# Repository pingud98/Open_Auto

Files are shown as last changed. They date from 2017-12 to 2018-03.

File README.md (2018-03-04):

# Open_Auto

Open Auto is an open hardware car sharing hardware platform designed for use by local car-sharing co-operatives and community associations. It originally started out as a Pi Hat, but has now changed into a standalone IOT device based on communications hardware from Particle.

The functionality is simple:
1) GPS tracking, allowing the car to be located at all times and used to update the onboard Real-time Clock (RTC)
2) RFID card access (125kHz or other frequency, requires an external module), with either CAN-bus or relays to open/close the car doors
3) Accelerometer to check driving style (requires an Electron)
4) RTC to allow for power saving (wake up once per minute to check status instead of continuously being on)
5) CAN bus interface for automotive communication
6) Particle Electron/Photon socket for Wi-Fi and/or Cellular connectivity
7) An SD card slot for data logging.
8) An I2C header for whatever else you want to connect.

We're currently working on a software stack for the Electron/Photon that will allow all the basic functions to be accessed via the particle API.

The design also includes a case, which you can make in 3mm acrylic. 

This design is licensed under the CERN Open Hardware License V1.2

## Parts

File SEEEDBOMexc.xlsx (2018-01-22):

Designator | Manufacturer Part Number | Quantity
J1 | A-DS 09 A/KG-T2S | 1
K1 | 311020024 | 1
RELAY1, RELAY2 | HLS8L-DC5V-S-C | 2
CHANNEL1, CHANNEL2 | GS009S-5.0-03P-11 | 2
R17 | RC0603JR-07100RL | 1
C1, C5, C8, C9, C12, C14, C16, C19, C22 | CC0603KRX7R9BB104 | 9
R3, R6, R18, R20, R32 | RC0603JR-0710KL | 5
R8, R9 | RC0603JR-0710RL | 2
C6, C21 | CC0603MRX5R5BB106 | 2
C17, C18 | CC0603JRNPO9BN100 | 2
C10 | CC0805KKX5R8BB106 | 1
R2, R7, R19 | RC0603FR-071KL | 3
D8 | 1SMB16CAT3G | 1
C3 | CC0603KRX7R8BB105 | 1
D5, D6 | B5819W | 2
C7 | CC0805MKX5R5BB226 | 1
R10, R11, R12, R13 | RC0603JR-073K9L | 4
R24, R25 | RC0603JR-072K2L | 2
C4 | C0805C474K5RACTU | 1
J3 | F185-1104A1BSYA1 | 1
R1 | RC0603FR-0768KL | 1
CN1, CN2, CN3 | F185-1106A1BSYC1 | 3
CN4, CN5 | P125-1103A1BS116A1 | 2
R21, R31, R33 | RC0603JR-074K7L | 3
U5 | A2235-H | 1
X4 | FC-135 | 1
D7 | BAT54S-7-F | 1
D12, D13 | 19-217-BHC-ZL1M2RY-3T | 2
BAT1 | BS-12-B3AA003 | 1
C11 | GRM219R61A226MEA0D | 1
D2, D3 | 1N4148 | 2
U3 | MMA7660FCR1 | 1
IC1 | NC7SZ14M5X | 1
IC3 | NCP1117LPST50T3G | 1
U8 | PCF85063TP/1Z | 1
D4 | PESD1CAN,215 | 1
D10, D11 | 19-217-R6C-AL1M2VY-3T | 2
D9 | RS1J-E3/5AT | 1
IC2 | TJA1049T-118 | 1
SDCARD | 1040310811 | 1
Q1, Q2 | S9013 | 2
P1, P2 | PPTC181LFBN-RC | 2
JP1, JP2 | 320190003 | 2

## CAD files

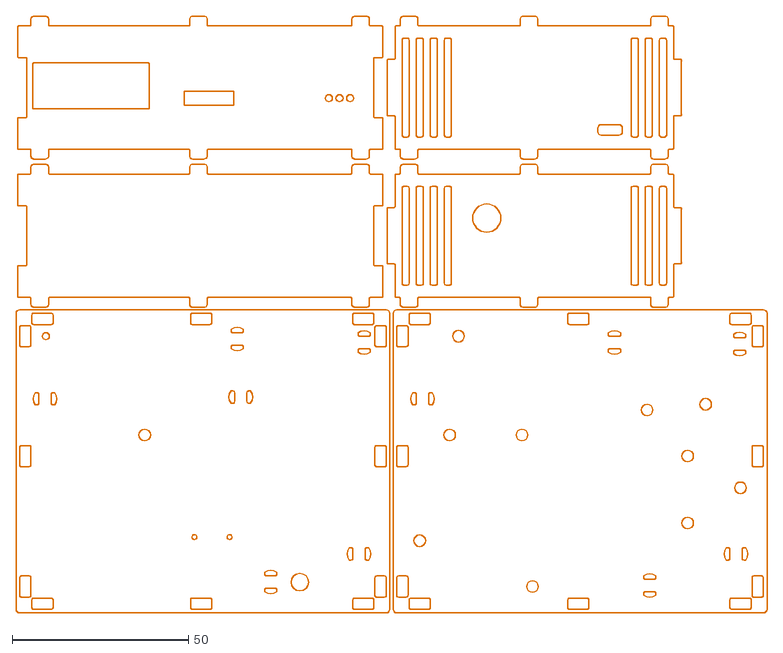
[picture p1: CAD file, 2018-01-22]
openautocaseproduction.dxf
213.0 x 169.3

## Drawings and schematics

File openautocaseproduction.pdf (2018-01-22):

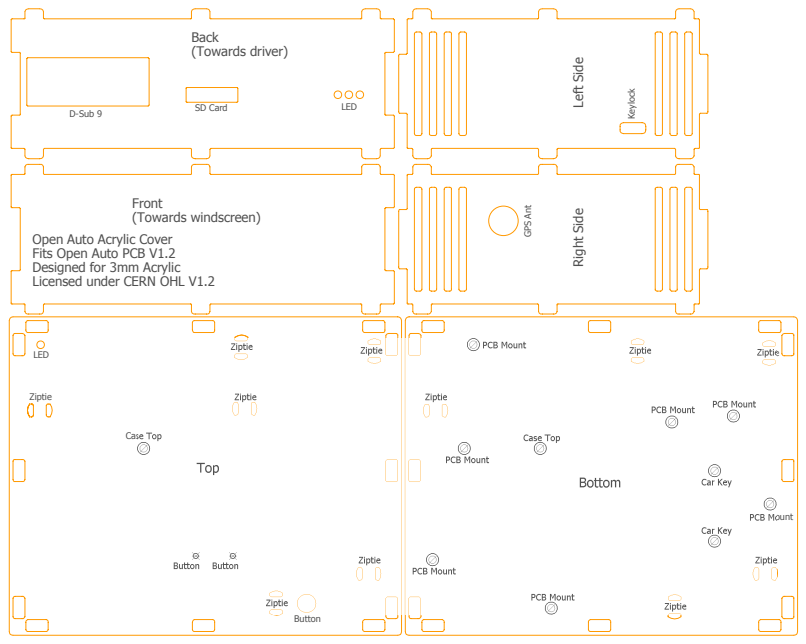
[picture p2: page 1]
Ziptie; Case Top; LED; Button; GPS Ant; D-Sub 9; Keylock; SD Card; Front (Towards windscreen); Back (Towards driver)

Right Side Left Side

Open Auto Acrylic Cover
Fits Open Auto PCB V1.2
Designed for 3mm Acrylic
Licensed under CERN OHL V1.2

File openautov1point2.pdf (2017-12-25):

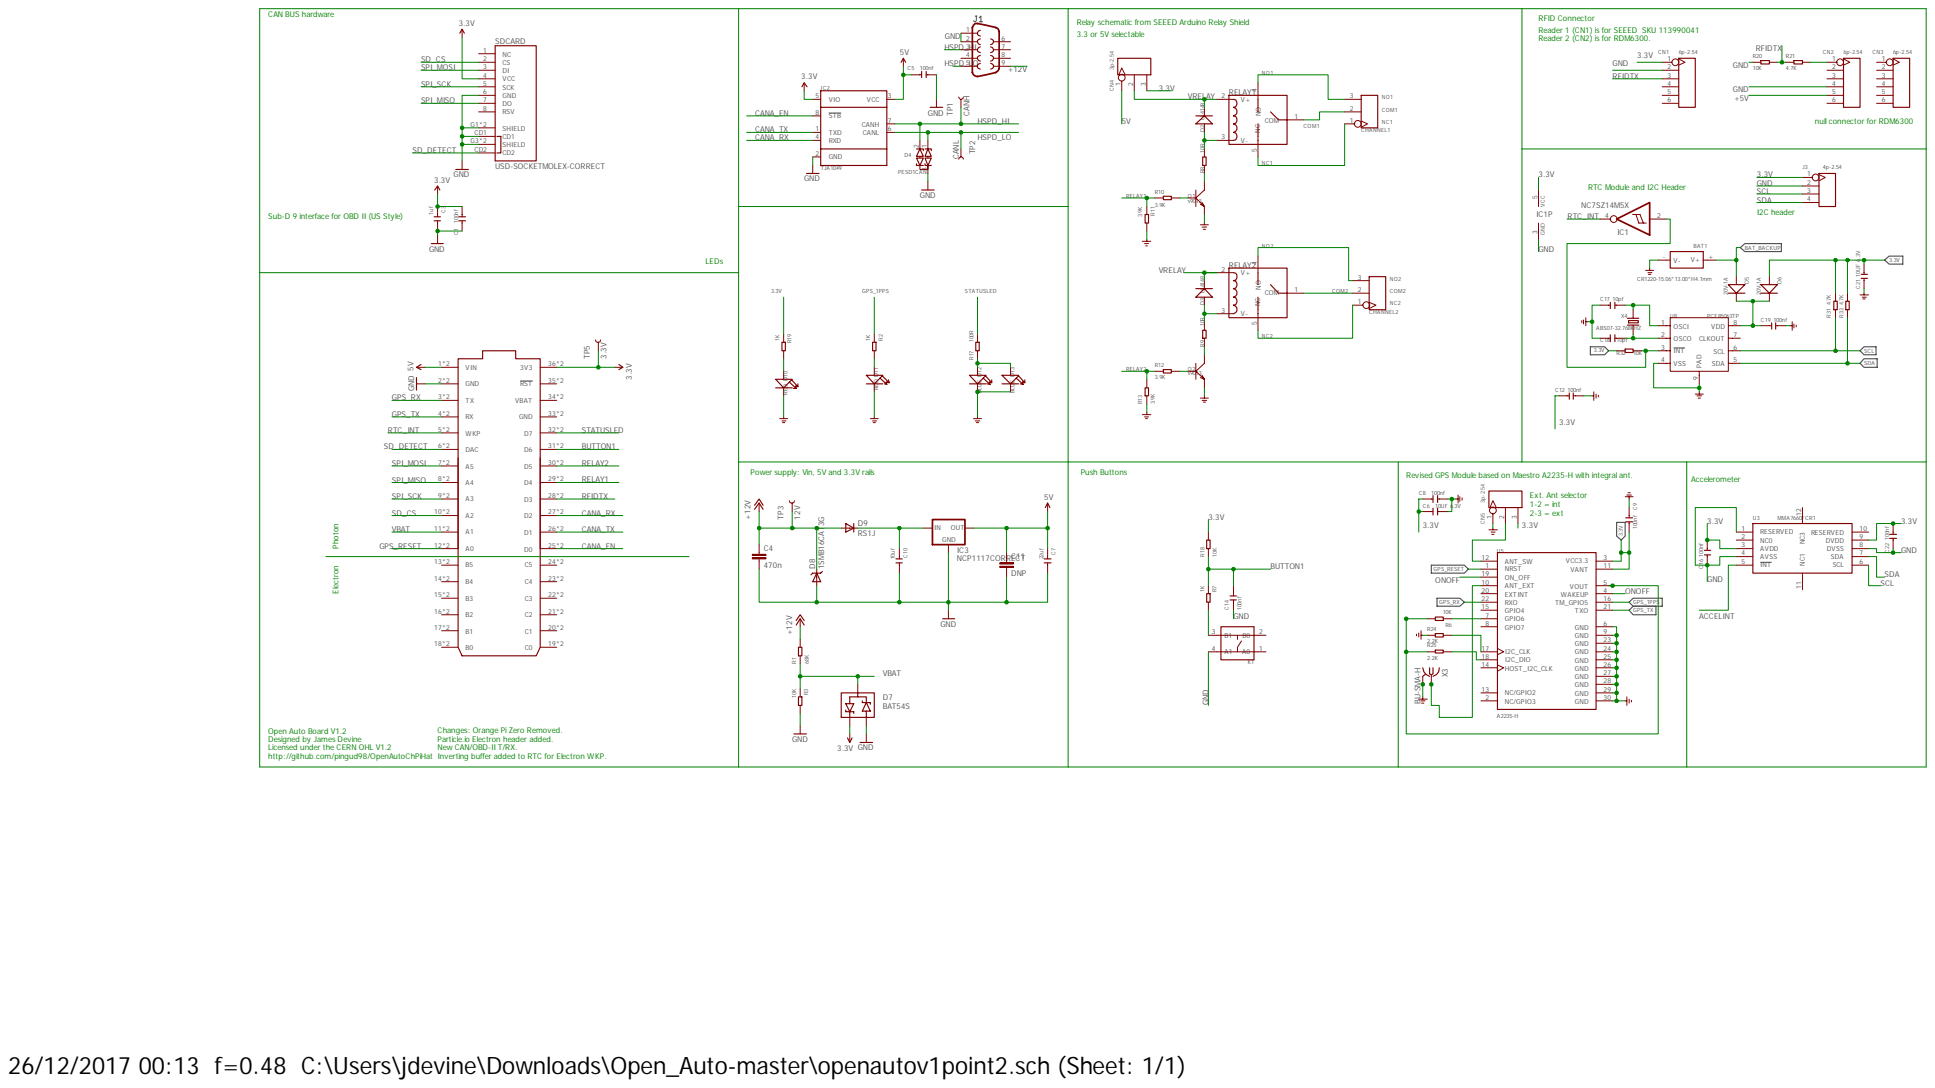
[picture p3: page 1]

Reader 1 (CN1) is for SEEED SKU 113990041
Reader 2 (CN2) is for RDM6300.

RTC Module and I2C Header

Sub-D 9 interface for OBD II (US Style)

Power supply: Vin, 5V and 3.3V rails

Revised GPS Module based on Maestro A2235-H with integral ant.

Open Auto Board V1.2
Designed by James Devine
Licensed under the CERN OHL V1.2
http://github.com/pingud98/OpenAutoChPiHat

Changes: Orange Pi Zero Removed.
Particle.io Electron header added.
New CAN/OBD-II T/RX.
Inverting buffer added to RTC for Electron WKP.

26/12/2017 00:13 f=0.48 C:\Users\jdevine\Downloads\Open_Auto-master\openautov1point2.sch (Sheet: 1/1)

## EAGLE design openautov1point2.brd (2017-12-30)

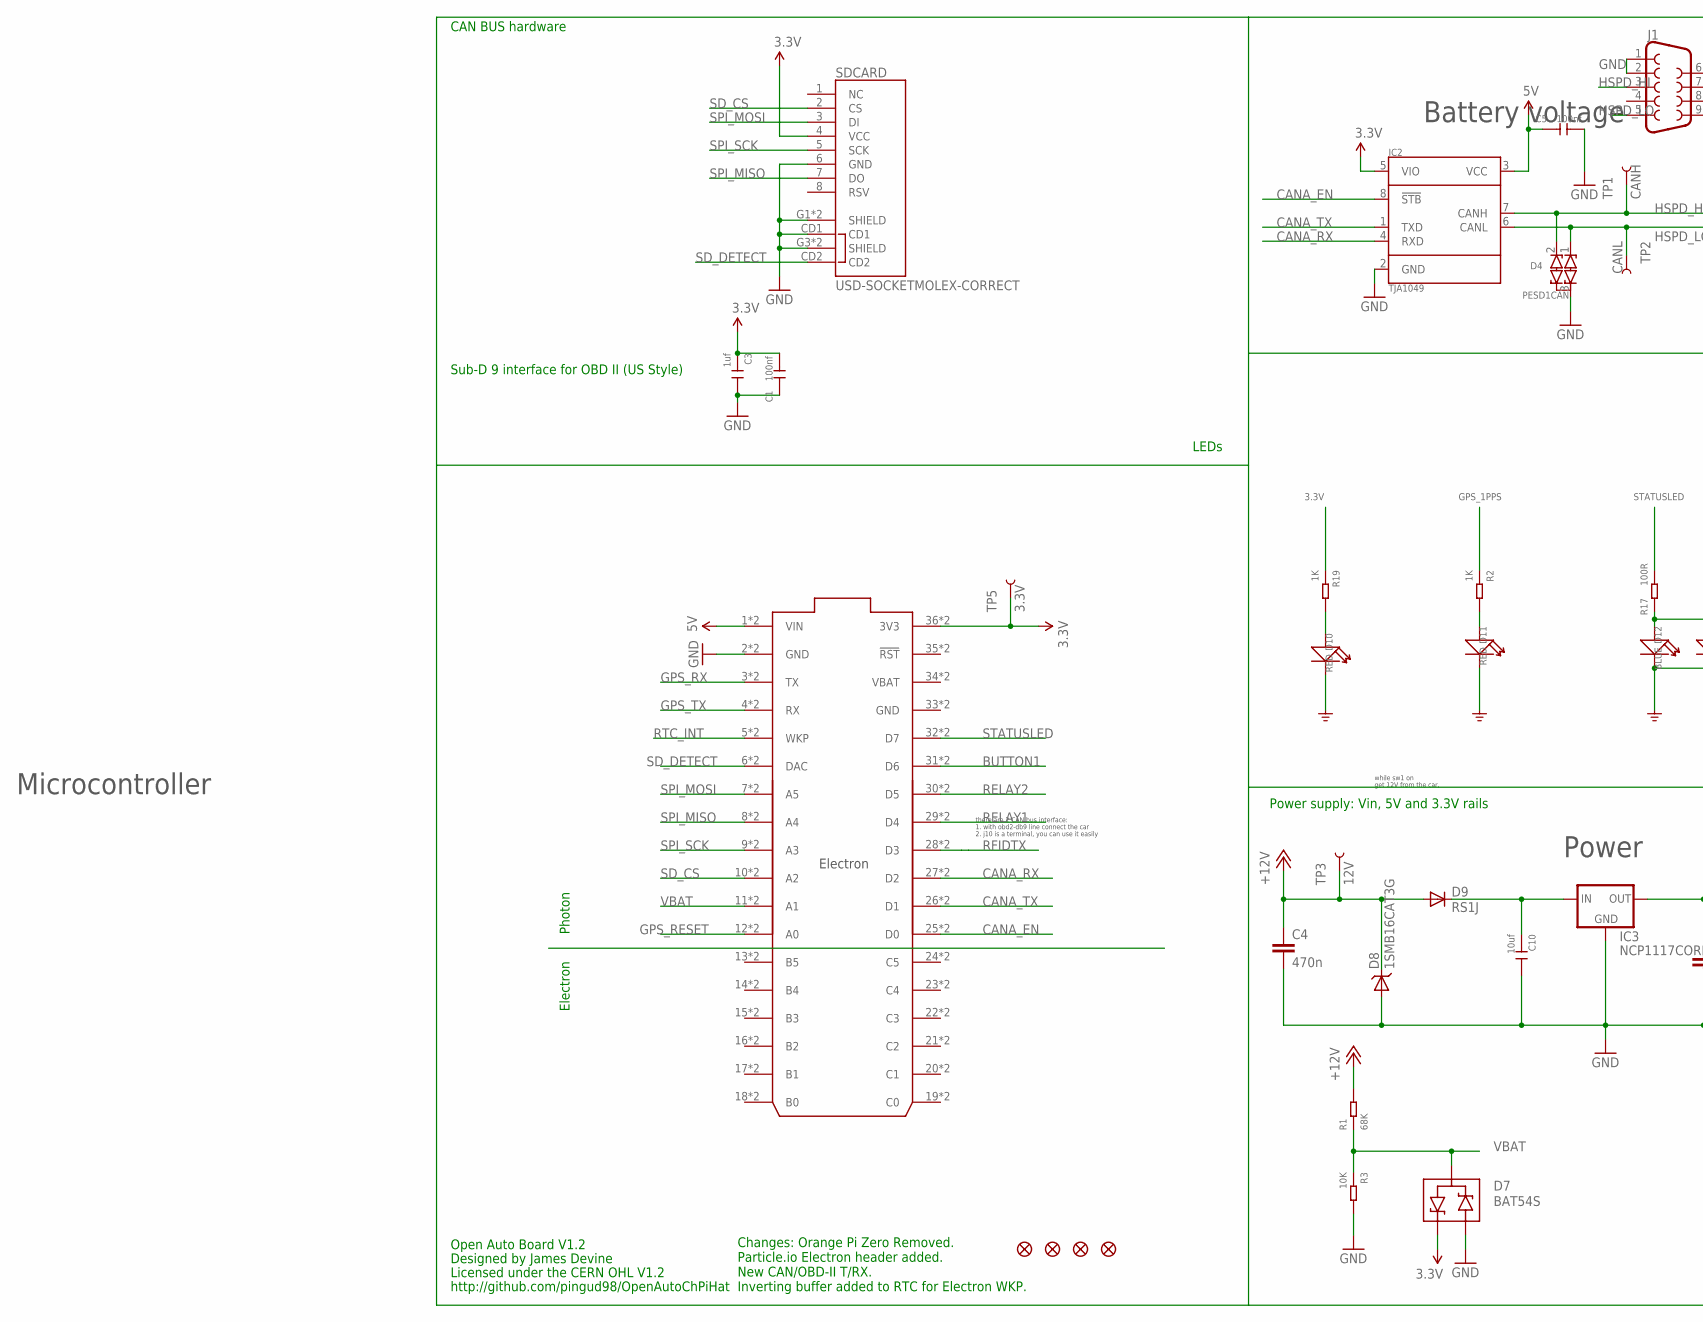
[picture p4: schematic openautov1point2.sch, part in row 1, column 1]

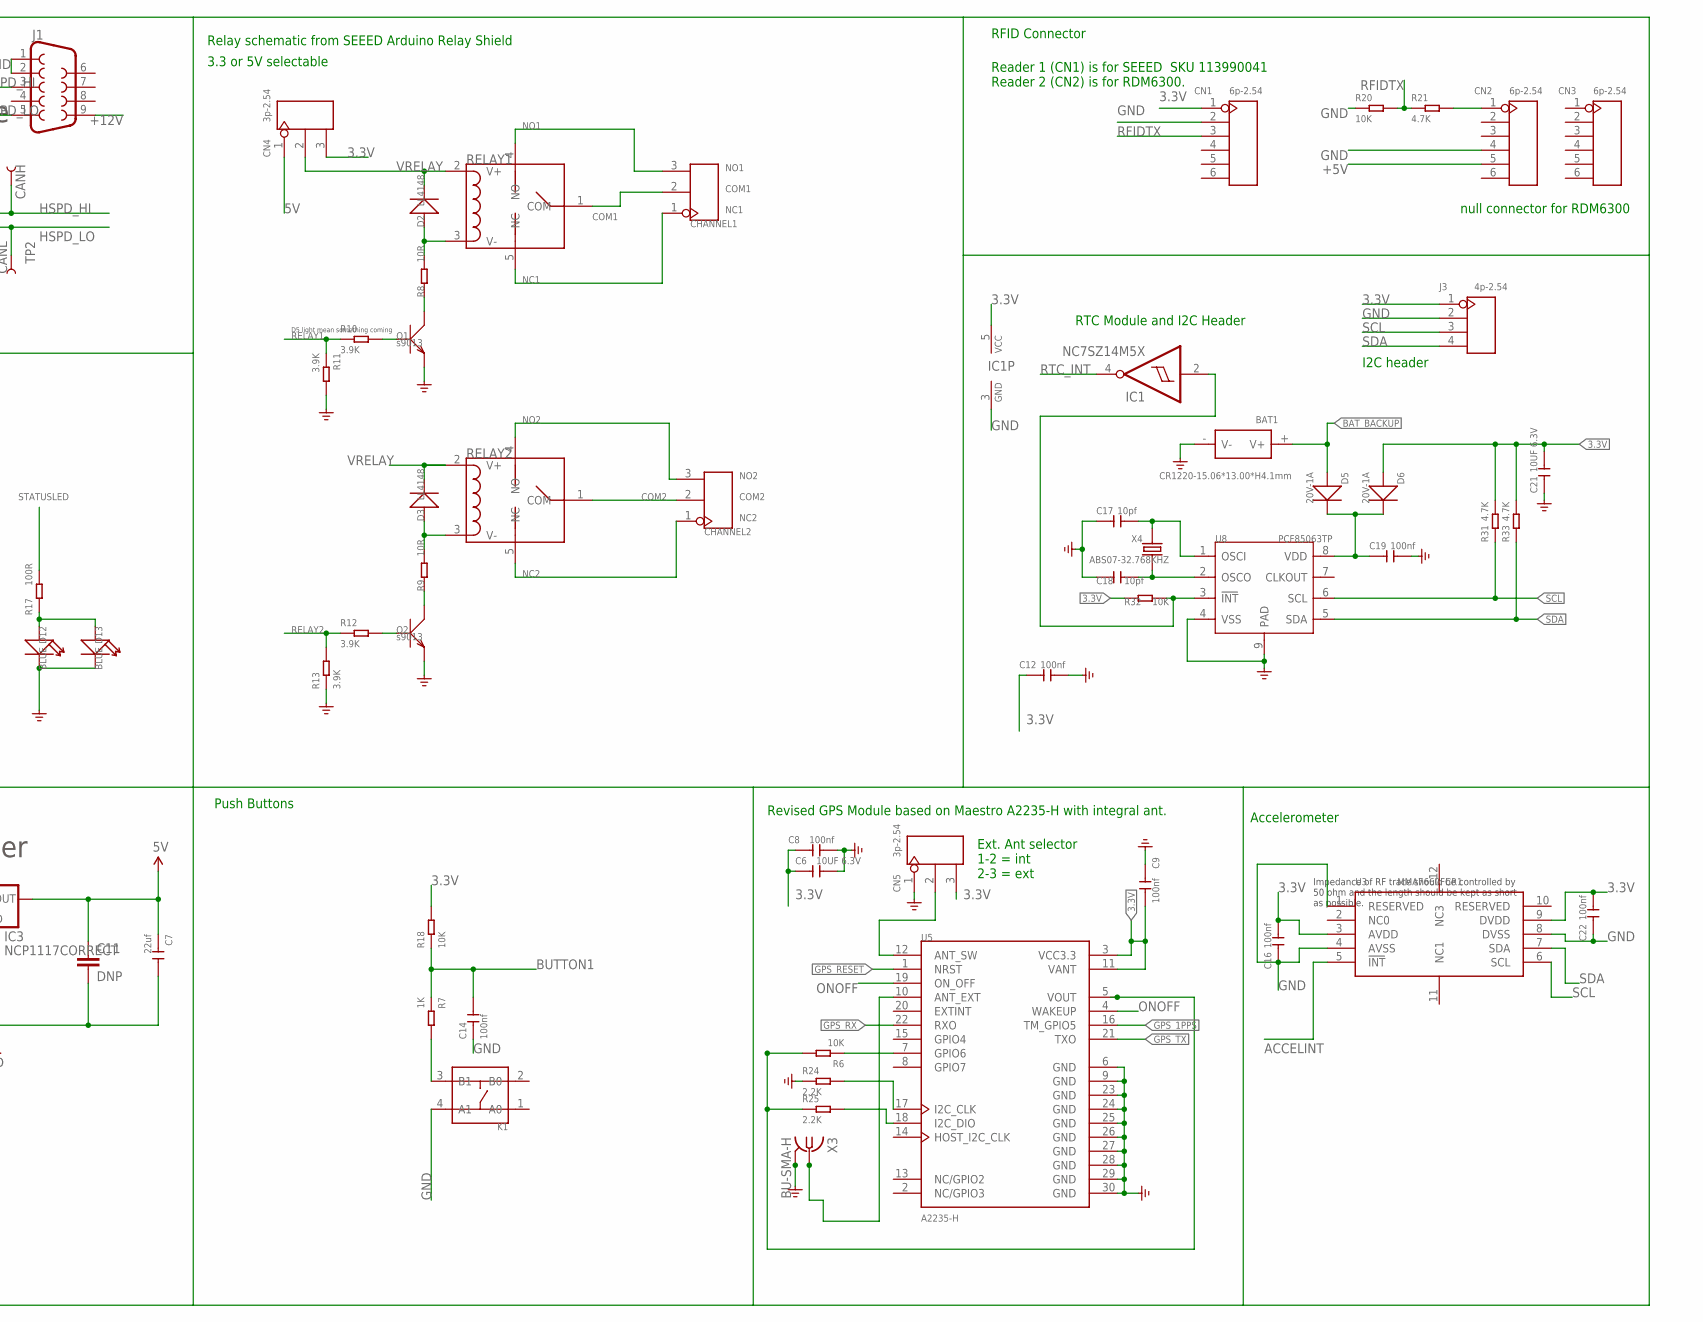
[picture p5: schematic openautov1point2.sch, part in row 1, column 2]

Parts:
BAT1: CR1220-15.06*13.00*H4.1mm; BAT2P-SMD-16.4-CR1220
C1, C5, C8, C9, C12, C14, C16, C19, C22: 100nf; C0603
C3: 1uf; C0603; PARTNO CC0805KKX7R7BB105
C4: 470n; C0805; PARTNO C0805C474K5RACTU
C6, C21: 10UF 6.3V; C0603
C7: 22uf; C0805; PARTNO GRM219R61A226MEA0D
C10: 10uf; C0805; PARTNO GRM21BR6YA106KE43L
C11: DNP; C0805; PARTNO GRM219R61A226MEA0D
C17, C18: 10pf; C0603
CHANNEL1, CHANNEL2: SCREW-TERMINAL-3P'3.5'; 3P-3.5
CN1, CN2, CN3: 6p-2.54; H6-2.54
CN4, CN5: 3p-2.54; H3-2.54
D2, D3: LL4148; LL-34
D4: PESD1CAN; SOT23; PARTNO PESD1CAN-215
D5, D6: 20V-1A; SOD-123
D7: BAT54S; SOT23; PARTNO BAT54S-7-F
D8: 1SMB16CAT3G; SMB-DIODE; PARTNO 1SMB16CAT3G
D9: RS1J; SMA-DIODE; PARTNO RS1J-E3/5AT
D10, D11: RED; LED-0603
D12, D13: BLUE; LED-0603
ELECTRON: ELECTRON_WITH_EXTERNAL_HEADERS; ELECTRON_EXTERNAL; PARTNO PPTC181LFBN-RC
FID1, FID2, FID3, FID4: FIDUCIAL1.5X3; FIDUCIAL-1.5X3
IC1: NC7SZ14M5X; SOT23-5
IC2: TJA1049; SO8; PARTNO TJA1049T-118
IC3: NCP1117CORRECT; SOT223; PARTNO NCP1117LPST50T3G
J1: DB9MALE; DB9_MALE
J3: 4p-2.54; H4-2.54
K1: DIP-SWITCH-TACTILE-SPST-NO/TS-1109(4P-D6.0MM)'TS-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; SW4-6.0X6.0X5.0MM
Q1, Q2: s9013; SOT23
R1: 68K; R0603; PARTNO ERJ-6ENF6202V
R2, R7, R19: 1K; R0603
R3, R6, R18, R20, R32: 10K; R0603
R8, R9: 10R; R0603
R10, R11, R12, R13: 3.9K; R0603
R17: 100R; R0603
R21, R31, R33: 4.7K; R0603
R24, R25: 2.2K; R0603
RELAY1, RELAY2: RELAY-HLS8L-DC5V-S-C; 5P-19.0X15.5X15.8H
SDCARD: USD-SOCKETMOLEX-CORRECT; MICRO-SD-MOLEX-CORRECT; PARTNO 1040310811
TP1: CANH; PAD.03X.03
TP2: CANL; PAD.03X.03
TP3: 12V; PAD.03X.03
TP5: 3.3V; PAD.03X.03
U3: MMA7660FCR1; DFN10-0.5-3.0X3.0MM
U5: A2235-H; XCVR_A2235-H
U8: PCF85063TP; HWSON8-0.5-2X3X0.75MM
X3: BU-SMA-H
X4: ABS07-32.768KHZ; X2-SMD-3.2X1.5X0.55MM

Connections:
3.3V: C1.2, C3.1, C6.1, C8.1, C9.2, C12.1, C16.2, C21.2, C22.2, CN1.1, CN4.3, D6.+, D7.2 (C1), ELECTRON.36 (3V3), ELECTRON.@36 (3V3), IC1.5 (VCC), IC2.5 (VIO), J3.1, R18.2, R19.1, R31.2, R32.1, R33.2, SDCARD.4 (VCC), TP5.P$1, U3.3 (AVDD), U3.9 (DVDD), U5.3 (VCC3.3), U5.11 (VANT)
5V: C5.1, C7.1, C11.1, CN4.1, ELECTRON.1 (VIN), ELECTRON.@1 (VIN), IC2.3 (VCC), IC3.2 (OUT), IC3.4 (OUT)
!RTC_INT: IC1.2 (I), R32.2, U8.3 (!INT)
+5V: CN2.5
+12V: C4.1, D8.C, D9.A, J1.9, R1.2, TP3.P$1
ACCELINT: U3.5 (!INT)
BAT_BACKUP: BAT1.+ (V+), D5.+
BUTTON1: C14.2, ELECTRON.31 (D6), ELECTRON.@31 (D6), R7.1, R18.1
CANA_EN: ELECTRON.25 (D0), ELECTRON.@25 (D0), IC2.8 (!STB)
CANA_RX: ELECTRON.27 (D2), ELECTRON.@27 (D2), IC2.4 (RXD)
CANA_TX: ELECTRON.26 (D1), ELECTRON.@26 (D1), IC2.1 (TXD)
COM1: CHANNEL1.2, RELAY1.1 (COM)
COM2: CHANNEL2.2, RELAY2.1 (COM)
GND: BAT1.- (V-), C1.1, C3.2, C4.2, C5.2, C6.2, C7.2, C8.2, C9.1, C10.2, C11.2, C12.2, C14.1, C16.1, C17.1, C18.1, C19.2, C21.1, C22.1, CN1.2, CN2.4, CN5.1, D4.3 (COM), D7.1 (A2), D8.A, D10.-, D11.-, D12.-, D13.-, ELECTRON.2 (GND), ELECTRON.33 (GND), ELECTRON.@2 (GND), ELECTRON.@33 (GND), IC1.3 (GND), IC2.2 (GND), IC3.1 (GND), J1.1, J1.2, J3.2, K1.4 (A1), Q1.2 (E), Q2.2 (E), R3.2, R11.2, R13.1, R20.1, R24.1, SDCARD.6 (GND), SDCARD.CD1, SDCARD.G1 (SHIELD), SDCARD.G2 (SHIELD), SDCARD.G3 (SHIELD), SDCARD.G4 (SHIELD), U3.1 (RESERVED), U3.4 (AVSS), U3.8 (DVSS), U5.6 (GND), U5.9 (GND), U5.23 (GND), U5.24 (GND), U5.25 (GND), U5.26 (GND), U5.27 (GND), U5.28 (GND), U5.29 (GND), U5.30 (GND), U8.4 (VSS), U8.9 (PAD), X3.2, X3.3 (2), X3.4 (2), X3.5 (2)
GPS_1PPS: R2.1, U5.16 (TM_GPIO5)
GPS_RESET: ELECTRON.12 (A0), ELECTRON.@12 (A0), U5.1 (NRST)
GPS_RX: ELECTRON.3 (TX), ELECTRON.@3 (TX), U5.22 (RXO)
GPS_TX: ELECTRON.4 (RX), ELECTRON.@4 (RX), U5.21 (TXO)
HSPD_HI: D4.2 (C2), IC2.7 (CANH), J1.3, TP1.P$1
HSPD_LO: D4.1 (C1), IC2.6 (CANL), J1.5, TP2.P$1
unnamed: K1.3 (B1), R7.2
unnamed: CN5.2, U5.12 (ANT_SW)
unnamed: Q2.1 (B), R12.2
unnamed: D3.A (+), R9.2, RELAY2.3 (V-)
unnamed: Q1.3 (C), R8.1
unnamed: D2.A (+), R8.2, RELAY1.3 (V-)
unnamed: Q2.3 (C), R9.1
unnamed: D11.+, R2.2
unnamed: D12.+, D13.+, R17.2
unnamed: U5.10 (ANT_EXT), X3.1
unnamed: R6.2, R25.1, U5.5 (VOUT)
unnamed: R6.1, U5.7 (GPIO6)
unnamed: Q1.1 (B), R10.2
unnamed: CN2.1, R21.2
unnamed: R24.2, U5.17 (I2C_CLK)
unnamed: R25.2, U5.18 (I2C_DIO)
unnamed: D10.+, R19.2
unnamed: C18.2, U8.2 (OSCO), X4.1
unnamed: C17.2, U8.1 (OSCI), X4.2
unnamed: C10.1, D9.C, IC3.3 (IN)
unnamed: C19.1, D5.-, D6.-, U8.8 (VDD)
NC1: CHANNEL1.1, RELAY1.5 (NC)
NC2: CHANNEL2.1, RELAY2.5 (NC)
NO1: CHANNEL1.3, RELAY1.4 (NO)
NO2: CHANNEL2.3, RELAY2.4 (NO)
ONOFF: U5.4 (WAKEUP), U5.19 (ON_OFF)
RELAY1: ELECTRON.29 (D4), ELECTRON.@29 (D4), R10.1, R11.1
RELAY2: ELECTRON.30 (D5), ELECTRON.@30 (D5), R12.1, R13.2
RFIDTX: CN1.3, ELECTRON.28 (D3), ELECTRON.@28 (D3), R20.2, R21.1
RTC_INT: ELECTRON.5 (WKP), ELECTRON.@5 (WKP), IC1.4 (O)
SCL: J3.3, R31.1, U3.6 (SCL), U8.6 (SCL)
SDA: J3.4, R33.1, U3.7 (SDA), U8.5 (SDA)
SD_CS: ELECTRON.10 (A2), ELECTRON.@10 (A2), SDCARD.2 (CS)
SD_DETECT: ELECTRON.6 (DAC), ELECTRON.@6 (DAC), SDCARD.CD2
SPI_MISO: ELECTRON.8 (A4), ELECTRON.@8 (A4), SDCARD.7 (DO)
SPI_MOSI: ELECTRON.7 (A5), ELECTRON.@7 (A5), SDCARD.3 (DI)
SPI_SCK: ELECTRON.9 (A3), ELECTRON.@9 (A3), SDCARD.5 (SCK)
STATUSLED: ELECTRON.32 (D7), ELECTRON.@32 (D7), R17.1
VBAT: D7.3 (COM), ELECTRON.11 (A1), ELECTRON.34 (VBAT), ELECTRON.@11 (A1), ELECTRON.@34 (VBAT), R1.1, R3.1
VRELAY: CN4.2, D2.C (-), D3.C (-), RELAY1.2 (V+), RELAY2.2 (V+)

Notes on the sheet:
D5 light mean something coming
CAN BUS hardware
there are 2 CAN bus interface:
1. with obd2-db9 line connect the car
2. j10 is a terminal, you can use it easily
Sub-D 9 interface for OBD II (US Style)
get 12V from the car,
while sw1 on
Relay schematic from SEEED Arduino Relay Shield
RFID Connector
Reader 1 (CN1) is for SEEED SKU 113990041 Reader 2 (CN2) is for RDM6300.
RTC Module and I2C Header
Impedance of RF trace should be controlled by 50 ohm and the length should be kept as short as possible.
Revised GPS Module based on Maestro A2235-H with integral ant.
LEDs
Open Auto Board V1.2
Designed by James Devine
Licensed under the CERN OHL V1.2
http://github.com/pingud98/OpenAutoChPiHat
Changes: Orange Pi Zero Removed. Particle.io Electron header added. New CAN/OBD-II T/RX. Inverting buffer added to RTC for Electron WKP.
Push Buttons
Accelerometer
Power supply: Vin, 5V and 3.3V rails
null connector for RDM6300
I2C header
Battery voltage
Microcontroller
Power
Photon
Electron
3.3 or 5V selectable
Ext. Ant selector 1-2 = int 2-3 = ext

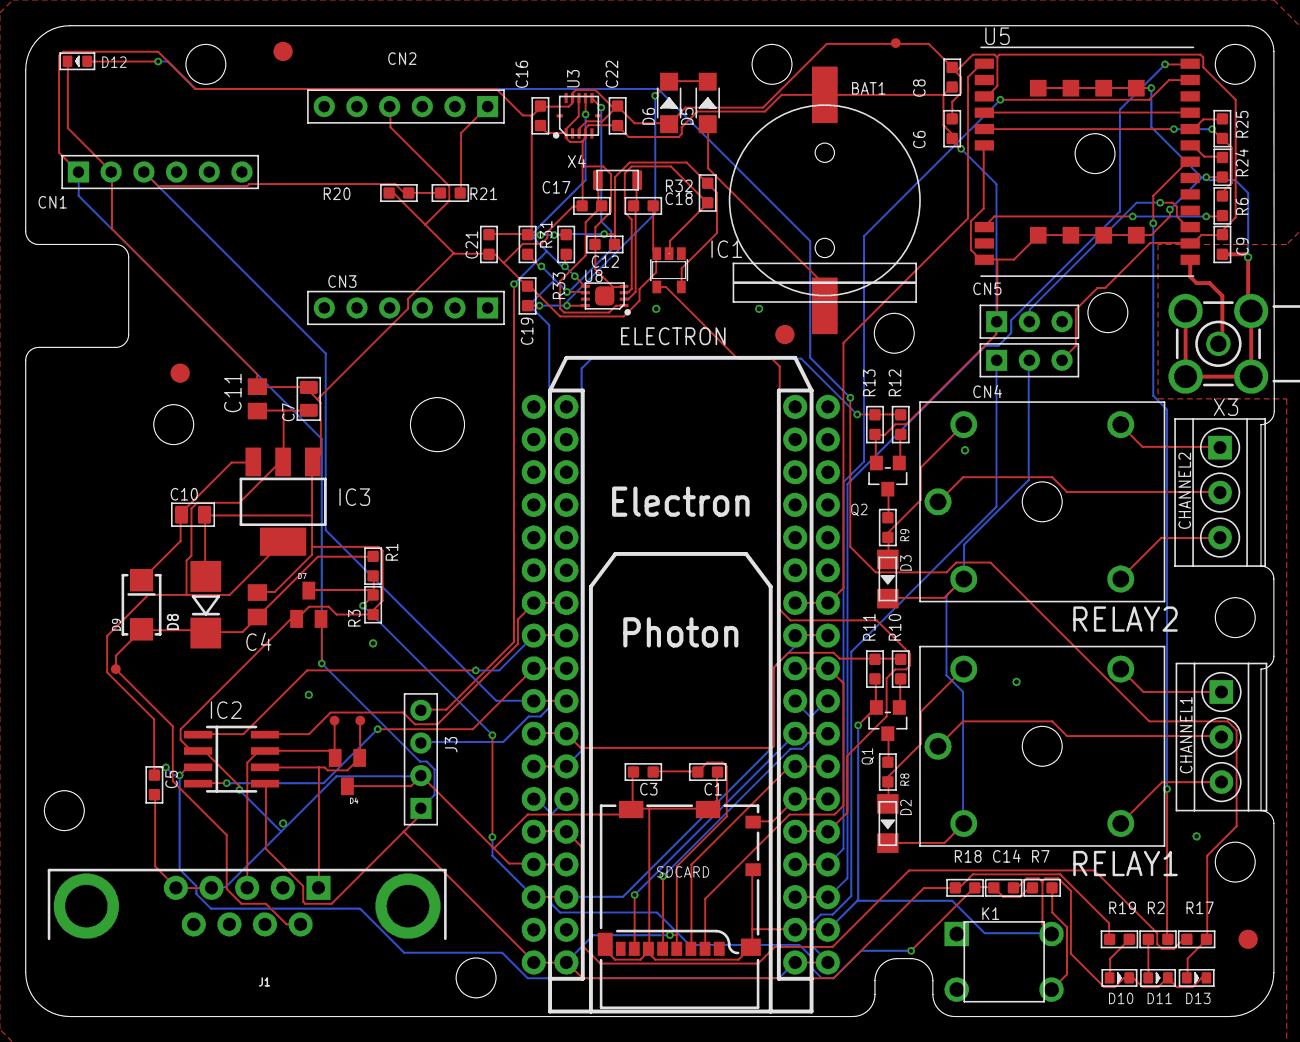
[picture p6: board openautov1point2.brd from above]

Board: 2 copper layers, 97.0 x 77.0 mm, 84 parts (0 on the bottom side), 58 nets.

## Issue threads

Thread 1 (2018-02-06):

Missing I2C connections

pingud98, 2018-02-06:
I2C is only connected to the I2C header, not the Electron/Photon. To be added; I2C functions will only work on the Electron due to pin constraints. Consider some kind of jumper/multiplexing.

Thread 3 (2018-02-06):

3V Relays - BOM change

pingud98, 2018-02-06:
Swap part HLS8L-DC5V-S-C for part HLS8L-DC3V-S-C. BOM Change only; 5V selector jumper can also be removed. This will enable unlocking even when the 5V supply from the car is off; highly useful for 100% autonomous operation if power from car is disconnected.

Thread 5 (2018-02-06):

OBD causes issues on Toyotas

pingud98, 2018-02-06:
Add documentation and firmware to ensure that OBD settings are correct/available for Toyota cars. As per https://priuschat.com/threads/obd-bluetooth-adapters-cause-abs-error.139701/

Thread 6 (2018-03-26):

Analogue read for battery voltage is too high

pingud98, 2018-03-26:
R3 needs to be changed for a smaller resistor, 5k would be better, or even 1k.

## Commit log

2017-12-11 Forking the openauto pi hat already
    New version based on the Particle.io Photon and Electron.
    Decided to ditch the name hat, since it isn't a hat anymore!
    [SEEEDBOMexc.xlsx, openautov1point2.brd, openautov1point2.sch]
2017-12-13 updated after design review
    [openautov1point2.brd, openautov1point2.sch]
2017-12-22 RDM6300 footprint corrected
    [openautov1point2.brd]
2017-12-24 Final update before Production, BOM still needs tidying
    [SEEEDBOMexc.xlsx, openautov1point2.brd, openautov1point2.sch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]
2017-12-25 Production versions
    [SEEEDBOMexc.xlsx, openautov1point2.brd, openautov1point2.sch]
2017-12-30 A 3mm laser cut acrylic case
    [openautocase2b.dxf]
2017-12-30 tidyup complete
    [work in progress.xlsx]
2017-12-30 added fiducials to PCB, created case
    [openautocase2b.brd, openautocase2b.dxf, openautocase2b.sch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]
2018-01-22 corrected parts for Ch1/2, X4 and C5
    [SEEEDBOMexc.xlsx]
2018-01-22 Added laser cut case, .brd + .dxf + annotated pdf
    [openautocaseproduction.brd, openautocaseproduction.dxf]

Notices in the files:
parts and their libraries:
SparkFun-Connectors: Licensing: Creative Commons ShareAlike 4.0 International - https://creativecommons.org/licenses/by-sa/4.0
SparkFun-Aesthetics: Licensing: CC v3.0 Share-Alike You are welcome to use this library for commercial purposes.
